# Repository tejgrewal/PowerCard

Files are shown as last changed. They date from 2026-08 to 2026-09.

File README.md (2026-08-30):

# PowerCard — Credit‑Card‑Sized Solar / Wireless Power Bank

**Status:** ✅ Validated design — main board (`PCB1`) has been fabricated and confirmed working by the designer. Schematics, full BOM, and enclosure/3D files are being prepared for publication (see [Roadmap](#roadmap)).

PowerCard is an open-hardware power bank designed to fit in a wallet: the board footprint matches an **ISO/IEC 7810 ID‑1 card (85.6 × 54 mm)**, and the target stack-up is roughly the thickness of two stacked credit cards. Everything lives on a single board (`PCB1`): it charges wirelessly (Qi-style coil) or from an integrated flexible solar film, stores energy in an ultra-thin 1 mm LiPo pouch cell, and outputs regulated 5 V directly over USB‑C.

Front of the PCB1 board — flexible solar film side
Back of the PCB1 board — wireless coil, battery and charge electronics

> The photos above show the fabricated `PCB1` board on an ESD mat, ruler for scale, populated with the wireless-charging, solar-charging, and boost/output electronics, mated to a 1 mm LiPo pouch cell and a PowerFilm flexible solar module.

---

## How it works

```
                 ┌─────────────────────────────────────┐
  ☀ Solar film   │                                     │
  (PowerFilm     │                                     │
   SP4.2-37) ────┤  U1  LTC4124                         │
                 │  (wireless Li-Ion charger,           │
  🔵 Qi coil ─────┤   ACIN + DCIN inputs)                │
  (on-board)     │                                     │
                 │  B1  1 mm LiPo pouch cell            │
                 │  (180 mAh, "954750")                 │
                 │                                     │
                 │  U3  LTC3246 (fixed 5V boost) ────────┼──▶ 5V USB-C
                 │                                     │
                 │  SW1 pushbutton, D1 status LED       │
                 │  J1 / U2  on-board FPC connector      │
                 └─────────────────────────────────────┘
                        single board — PCB1
```

* **Input 1 — Wireless charging:** an on-board coil feeds **U1, an Analog Devices/Linear Technology LTC4124** — a 100 mA wireless Li‑Ion charger with integrated PowerPath control and low-battery disconnect. It charges the cell from an external Qi-style/resonant transmitter coil held against the card, via the IC's **ACIN** pin (an internal diode routes AC-tank power to VCC).
* **Input 2 — Solar:** a **PowerFilm SP4.2‑37** flexible amorphous-silicon film (92 mW, 4.2 V / 22 mA in full sun, ~0.2 mm thick, up to ~6.5 V open-circuit) is laminated to the same board, feeding the LTC4124's **DCIN** pin — the IC's dedicated direct-DC input, separate from the coil/ACIN path. Confirmed working by the designer.
* **Storage:** a **1 mm-thick, 180 mAh LiPo pouch cell** (marked `HZ 954750`, 3.7 V nominal), sourced from a generic overseas cell vendor. See [`SAFETY.md`](SAFETY.md) for general handling guidance — standard good practice for any lithium pouch cell project.
* **Output:** **U3, an LTC3246MPMSE** switched-capacitor (inductor-less) buck-boost converter, configured for a fixed regulated 5 V rail, feeding the USB‑C output connector directly on `PCB1`. Confirmed working at 5V fixed output by the designer.
* **UI:** one status LED (`D1`) and one tactile pushbutton (`SW1`).
* **On-board connector:** one FPC connector (`J1`, mating part `U2`) is present on the board — see [`BOM.md`](BOM.md) for the part number; its exact function will be documented once the schematic is published.

## Repository layout

```
PowerCard/
├── README.md                  ← you are here
├── SAFETY.md                  ← battery & solar safety notes — read before building
├── BOM.md                     ← bill of materials (as supplied so far)
├── CONTRIBUTING.md
├── CHANGELOG.md
├── LICENSE                    ← hardware license (CERN-OHL-S-2.0)
├── LICENSE-DOCS                ← documentation license (CC-BY-4.0)
├── docs/
│   └── images/                ← board photos
├── hardware/
│   ├── pcb1-main-board/
│   │   ├── gerbers/           ← RS-274X Gerbers + Excellon drill (as fabricated)
│   │   └── fab-outputs/       ← fab report (.REP), drill report (.DRR), extension map
│   └── schematics/            ← placeholder — schematics to be added
└── .github/                   ← issue templates
```

## Board specifications (as measured from the supplied Gerbers)

| Parameter | Value |
|---|---|
| Board outline | 85.0 mm × 54.05 mm (ID‑1 credit-card footprint) |
| Layers | 2 (Top + Bottom copper, top/bottom silkscreen, soldermask, paste) |
| Surface finish | ENIG (per designer) |
| Drills | 49× Ø0.20 mm, 1× Ø0.45 mm, 2× Ø1.0 mm (52 total, all plated) |
| CAD tool | Altium Designer 26.3.0, project "CC Solar" |
| Fab data generated | 2026‑07‑20 |
| Board thickness | *Not encoded in the Gerber set — confirm with your fab and document here once the target overall card thickness (with the 1 mm cell stacked in) is finalized.* |

Full Gerber/drill files: [`hardware/pcb1-main-board/gerbers/`](hardware/pcb1-main-board/gerbers/)

## Bill of materials

A BOM (as supplied by the designer, Digi-Key part numbers) is in [`BOM.md`](BOM.md). A schematic with net-level cross-referencing is in progress — see [`hardware/schematics/`](hardware/schematics/).

## What's still being published

The design itself is validated and working, on a single board. The following documentation/files are still being prepared:

1. **Schematic** — not yet published. The BOM and photos document the working design, but a schematic will make it easier for others to build from scratch, and will clarify what the on-board FPC connector (`J1`/`U2`) is used for.
2. **Board/stack thickness measurements** — "thin as two credit cards" is the design target; exact board thickness and total assembled thickness (with the 1 mm cell) will be documented once measured/finalized.
3. **Full, schematic-cross-checked BOM** — the current BOM (below) is accurate to the fabricated board but hasn't yet been tied to net names in a published schematic.

If you're the designer, treat this as the top of the roadmap. If you're a visitor building from this repo in the meantime, the photos + BOM are your best reference until the schematic lands — see [`docs/hardware-overview.md`](docs/hardware-overview.md).

## Roadmap

- [ ] Publish schematic
- [ ] Publish complete BOM cross-checked against schematic net names
- [ ] Document the on-board FPC connector's (`J1`) function
- [ ] Measure and document board and total assembled stack thickness
- [ ] Post assembly photos and a bring-up/test procedure
- [ ] Add STEP/3D models

## License

Hardware design files (Gerbers, and future schematics/PCB source) are released under the **CERN Open Hardware Licence Version 2 – Strongly Reciprocal (CERN-OHL-S-2.0)** — see [`LICENSE`](LICENSE).

Documentation (this README, `docs/`, etc.) is released under **Creative Commons Attribution 4.0 (CC-BY-4.0)** — see [`LICENSE-DOCS`](LICENSE-DOCS).

Referenced part numbers, datasheets, and manufacturer names (Analog Devices/Linear Technology, PowerFilm, Digi-Key, etc.) remain the property of their respective owners; this project simply documents how they are used together.

## Contributing

See [`CONTRIBUTING.md`](CONTRIBUTING.md). Bug reports, schematic reviews, and safety feedback are especially welcome while the design is in preview.

## Safety

See [`SAFETY.md`](SAFETY.md) for general handling guidance for the lithium-polymer pouch cell, wireless charging, and solar input — standard good practice for any small lithium battery project, regardless of how well-validated the design is.

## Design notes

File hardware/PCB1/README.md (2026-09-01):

# PCB1 — Main Card Board

This is the main card-shaped PCB: wireless-charging receiver, boost/output regulator, battery connection, status LED, and pushbutton, on an 85.0 × 54.05 mm outline (ISO/IEC 7810 ID-1 credit-card footprint).

## Contents

- [`gerbers/`](gerbers/) — RS-274X Gerber layers + Excellon (`.TXT`) drill file, exactly as generated for fabrication (Altium Designer 26.3.0, project name "CC Solar", generated 2026-07-20). Also includes the Altium aperture files (`.apr`, `.APR_LIB`) and layer-pair export (`.LDP`) that were bundled with the fab export.
- [`../fab-outputs/`](../fab-outputs/) — the fab/drill reports (`.REP`, `.EXTREP`, `.DRR`) generated alongside the Gerbers, useful for a quick sanity check of layer count, drill sizes, and aperture usage without opening a Gerber viewer.

## Layer map

| File | Layer |
|---|---|
| `PCB1.GTL` | Top copper |
| `PCB1.GBL` | Bottom copper |
| `PCB1.GTO` | Top silkscreen |
| `PCB1.GBO` | Bottom silkscreen |
| `PCB1.GTS` | Top soldermask |
| `PCB1.GBS` | Bottom soldermask |
| `PCB1.GTP` | Top paste |
| `PCB1.GBP` | Bottom paste |
| `PCB1.GM` | Board outline / profile |
| `PCB1.GM9` | Board shape (mechanical) |
| `PCB1.TXT` | Excellon drill file (metric, leading zeros) — 49× Ø0.20 mm, 1× Ø0.45 mm, 2× Ø1.0 mm, all plated |

## Viewing the Gerbers

Any Gerber viewer will work — for a quick browser-based look without installing anything, try [Tracespace](https://tracespace.io/view/) or [GerbLook](http://www.gerblook.org/); for a full-featured desktop viewer, [KiCad's Gerber Viewer](https://www.kicad.org/) (free) or your fab's own viewer both work well.

## What's not here yet

Schematic source and native Altium PCB source (`.PcbDoc`/`.SchDoc`) are still being prepared for publication — see the [top-level README's Roadmap](../../README.md#roadmap). The board itself is fabricated and confirmed working.

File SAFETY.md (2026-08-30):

# Safety Notes

This project uses a lithium-polymer pouch cell, a wireless-power receiver, and a flexible solar film in a thin, flexible, wallet-carried card. The design has been fabricated and validated by the designer. This document covers general good-practice handling for lithium pouch cells and this design's charging inputs — worth reading once regardless of how validated a design is, since it's really about how *you* handle a cell day to day, not a doubt about the design itself.

## Battery handling

- The cell used (`HZ 954750`, 1 mm thick, 180 mAh, 3.7 V) is an ultra-thin pouch cell. As with any thin pouch cell, avoid flexing, puncturing, or crushing the assembled card near the battery, and don't laminate/seal the pouch in a way that prevents it from venting if it ever needs to.
- Physically inspect cells before first use: swelling, punctures, discoloration, or a chemical smell are all reasons to set that cell aside.
- Charge new prototypes on a fireproof surface, away from flammable materials, for the first several cycles until you're familiar with how the board behaves.

## Wireless charging and solar input

- The LTC4124 accepts power from a matched wireless-power transmitter coil on its **ACIN** pin, and from the solar film on its **DCIN** pin — two separate, intended input paths on the same charger IC. Use a transmitter intended for low-power (sub-1 W to few-W) Qi-style or resonant wireless charging.
- Worth a quick check once the schematic is published (mostly for anyone else building this from the repo): the LTC4124's DCIN/VCC/BAT absolute maximum rating is 6 V, and the SP4.2‑37's open-circuit voltage can reach roughly 6.5 V in full sun with no load. Documenting how that margin is handled (likely via `R1`) will help other builders trust the design without having to re-derive it themselves.

## General handling

- Treat the assembled card the same way you'd treat any other small lithium battery project: no charging inside a pocket, bag, or under a pillow; no charging near paper/fabric.
- If a cell ever swells, gets hot, or smells strange, disconnect it, move it to a safe non-flammable area, and let it fully discharge/cool before disposal via a battery recycling program — don't throw it in household trash.

## Contributing safety improvements

If you spot something worth adding here as the design evolves, please open an issue (see [`CONTRIBUTING.md`](CONTRIBUTING.md)) — safety documentation for an open-hardware project only works if it stays current.

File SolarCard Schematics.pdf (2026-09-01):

# Solar Power Card

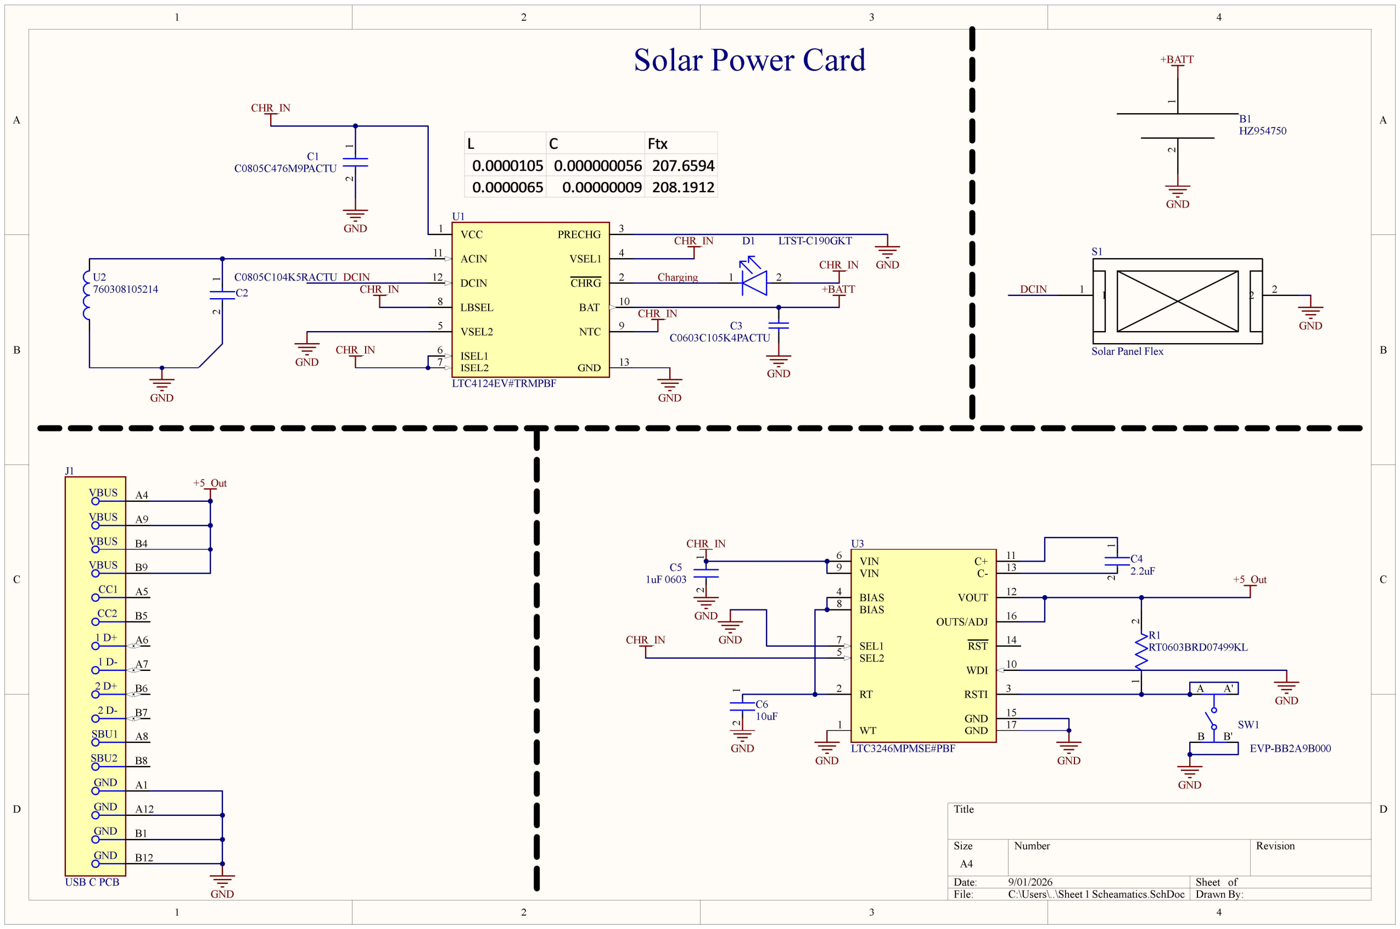
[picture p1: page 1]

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
Title

Size | Number | Revision
A4
Date: | 9/01/2026 | Sheet of
File: | C:\Users\..\Sheet 1 Scheamatics.SchDoc Drawn By:

VCC 1

VSEL1 4

VSEL2 5

ISEL1 6
ISEL2 7

CHRG 2

ACIN 11

BAT 10

DCIN 12

LBSEL 8

NTC | 9
PRECHG | 3
GND | 13

U1

LTC4124EV#TRMPBF
GND | GND
Charging | 1 | 2
D1 | LTST-C190GKT ¹ ²
C1
C0805C476M9PACTU

GND

C3
C0603C105K4PACTU

GND

GND ¹ ²
C2

C0805C104K5RACTU

CHR_IN

CHR_IN

CHR_IN
U2
760308105214 | CHR_IN

CHR_IN

CHR_IN

+BATT

GND

VIN 6
VIN 9

BIAS 4
BIAS 8

SEL1 7
SEL2 5
RST | 14
C+ | 11
C- | 13
RSTI | 3 RT 2
VOUT | 12
WDI | 10

WT 1

GND | 15
GND | 17
OUTS/ADJ | 16

U3

LTC3246MPMSE#PBF

CHR_IN

CHR_IN | GND

GND

GND

1 2
C4
2.2uF
+5_Out 1 2

C6
10uF

GND

1 2
C5
1uF 0603

GND

GND

B B'

A A'

SW1

EVP-BB2A9B000

# GND ¹ ² R1

RT0603BRD07499KL

+5_Out

GND

1

1
2

2

S1

Solar Panel Flex

DCIN
DCIN

GND

1 2
B1
HZ954750

GND

+BATT

GND

VBUS

CC1

### 1 D+

### 1 D-

SBU1

VBUS

GND

GND

VBUS

CC2

### 2 D+

### 2 D-

SBU2

VBUS

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
USB C PCB

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
Title

Size | Number | Revision
A4
Date: | 9/01/2026 | Sheet of
File: | Sheet1.SchDoc | Drawn By:

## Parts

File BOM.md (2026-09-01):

| Comment | Description | Designator | Footprint | LibRef | Quantity |
|---|---|---|---|---|---|
| HZ954750 | 3.7V 180mA | B1 | HZ954750-Footprint-1 | CMP-00029-00001-1 | 1 |
| C0805C476M9PACTU | CAP CER 47UF 6.3V X5R 0805 | C1 | FP-C0805C476M9PACTU-MFG | CMP-2007-01008-2 | 1 |
| C0805C104K5RACTU | CAP CER 0.1UF 50V X7R 0805 | C2 | FP-C0805C-DN-MFG | CMP-2007-00279-2 | 1 |
| C0603C105K4PACTU | CAP CER 1UF 16V X5R 0603 | C3 | CAPC1608X90X35NL15T15 | CMP-2006-02239-1 | 1 |
| 2.2uF | GRM188R71A225KE15D Chip Multilayer Ceramic Capacitors for General Purpose, 0603, 2.2uF, X7R, 15%, 10%, 10V | C4 | FP-GRM188-0_1-e0_2_0_5-MFG | CMP-2006-02836-2 | 1 |
| 1uF 0603 | C0603C105K3PACTU CAP CER 1UF 25V X5R 0603 | C5 | FP-C0603C105K3PACTU-MFG | CMP-2006-02216-3 | 1 |
| 10uF | GRM188R60J106ME47D Chip Multilayer Ceramic Capacitors for General Purpose, 0603, 10uF, X5R, 15%, 20%, 6.3V | C6 | FP-GRM188-0_1-e0_2_0_55-IPC_A | CMP-2006-02792-2 | 1 |
| LTST-C190GKT | LED GREEN CLEAR CHIP SMD | D1 | FP-LTST-C190GKT-MFG | CMP-22017-000005-2 | 1 |
| 760308105214 | General Purpose Inductor | gnd | 760308105214 | CMP-021-00007-2 | 1 |
| USB C PCB | | J1 | New footprint 1 | CMP-002-00261-5 | 1 |
| RT0603BRD07499KL | RES SMD 499K OHM 0.1% 1/10W 0603 | R1 | FP-RT0603-MFG | CMP-03412-000773-1 | 1 |
| Solar Panel Flex | | S1 | Solar Panel Flex-Footprint-1 | CMP-002-00262-1 | 1 |
| EVP-BB2A9B000 | SWITCH TACTILE SPST-NO 0.02A 15V | SW1 | FP-EVP-BB2A9B000-MFG | CMP-05618-000013-1 | 1 |
| LTC4124EV#TRMPBF | IC BATT CHG LI-ION 1CELL 12LQFN | U1 | FP-LQFN-12-05-08-1530-IPC_C | CMP-09132-000015-1 | 1 |
| LTC3246MPMSE#PBF | LTC3246MPMSE#PBF Charge Pump INV/STPUP/STPDN 2.5V to 5V/3.3V/5V 0.5mA Automotive 16-Pin MSOP EP Tube | U3 | FP-MSE-16-05-08-1667-MFG | CMP-00026-88967362-1 | 1 |

| Item | Notes |
|---|---|
| Battery (B1) | 1 mm-thick LiPo pouch cell, printed marking `HZ 954750`, 3.7 V nominal, 180 mAh, sourced from [battery-vats.sell.everychina.com](https://battery-vats.sell.everychina.com/). No Digi-Key/distributor part number — see [`SAFETY.md`](SAFETY.md) regarding sourcing generic thin cells. |
| Solar film | PowerFilm **SP4.2-37** — 92 mW / 4.2 V / 22 mA (full sun), 84 × 37 mm active area, ~0.2 mm thick flexible amorphous-silicon module. Digi-Key/Mouser stock this part;SP4.2-37. |

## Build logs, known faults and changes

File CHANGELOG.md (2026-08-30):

# Changelog

All notable changes to this project will be documented in this file.
This project doesn't yet follow a formal versioning scheme (it's pre-release hardware) — dates are used until a v1.0 hardware release is tagged.

## [Unreleased]

### Changed
- Updated project status from "early preview" to "validated, working design" per designer confirmation that the fabricated board operates as intended (wireless + solar charging via the LTC4124's ACIN/DCIN inputs, and the LTC3246 5V fixed output stage).
- Reframed documentation from "known gaps / don't build yet" to "in-progress publication items" (schematic, USB-C daughter board files, stack thickness measurements) — the design works, these are documentation/publication tasks, not open engineering questions.
- Softened SAFETY.md to general good-practice guidance for lithium pouch cells and this design's charging inputs, rather than unresolved-risk framing.

### Added
- Initial public repository structure.
- `PCB1` main-board Gerbers and Excellon drill file, as fabricated (Altium Designer 26.3.0, project "CC Solar", fab data generated 2026-07-20).
- Fab reports (`.REP`, `.EXTREP`, `.DRR`) for the main board.
- Board photos (front/solar side, back/electronics side).
- Preview `BOM.md` covering `U1`–`U3`, passives, LED, and switch, sourced from the designer's Digi-Key parts list.
- `SAFETY.md` covering battery, wireless-charging, and solar-input safety considerations.
- `README.md` describing the overall architecture and the known documentation gaps.

### Known gaps (tracked, not yet resolved)
- Schematics not yet published.
- USB-C output daughter board files not yet added.
- Board/stack thickness measurements not yet documented.

See the README's [Roadmap](README.md#roadmap) for what's planned next.

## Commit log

2026-08-30 Initial PowerCard documentation and configuration files
2026-08-30 docs: update README to reflect PCB1 as single-board validated design and harmonize wording; reference SAFETY.md clarifications
2026-09-01 Revise BOM with new parts and specifications
    Updated the Bill of Materials to include new components and their specifications, while removing outdated entries.
2026-09-01 Add PCB1 hardware documentation
2026-09-01 Create PCKPLACE file with PCB design details
    Added design information and component details for PCB layout.
